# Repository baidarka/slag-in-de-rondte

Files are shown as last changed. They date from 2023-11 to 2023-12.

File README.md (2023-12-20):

# README

## Intro

The board game '[Slag in de Rondte](https://www.slaginderondte.nl/spel)' is played on a map of the Dutch Wadden Sea.  
Sail to all isles (use of engine or GPS is not allowed) and return to Harlingen. Day and night. Fastest wins.  
This project lights up the lighthouses (using real world characteristics)!

Slag in de Rondte extension (https://youtu.be/sG-JDIeeyXA)

This [repository](https://github.com/baidarka/slag-in-de-rondte) contains MicroPython code to fade multiple LEDs independently.  
Written for, and tested on, [Raspberry Pi Pico](https://www.raspberrypi.com/documentation/microcontrollers/raspberry-pi-pico.html).

The board game uses a day/night cycle of about eight minutes.
Switch off your room lights when the lighthouses come on.
And turn your room lights back on, when the lighthouses switch off. (note: an 'always on' mode is available)

## Getting started

Get started with your Raspberry Pi Pico: <https://projects.raspberrypi.org/en/projects/getting-started-with-the-pico>

### part 1

For lookenspeepers, build this project and watschen der Blinkenlichten!

- Wire up your RPI Pico according to the Fritzing diagram below
- (optional: ground GPIO2 with a resistor to bypass the 8 minutes day/night cycle and be 'always on')
- Save the script 'slag-in-de-rondte.py' to your Pico as 'main.py'
- Restart your Pico

YouTube, the plain RPI Pico project:  
Slag in de Rondte, plain RPI Pico project (https://youtu.be/appXGaQrQTM)

### part 2

After finishing part 1, install the LED's in the game board.

- Solder cheap speaker cable to the LEDs, to extend their connectors
- Gently punch holes in the game board at the 5 island lighthouses, and Harlingen Harbor
- Place the LED's in the board game
  (use the red and green LEDs at Harlingen Haven)
- Connect the LED wires to your breadboard as before
  (do not change the circuit, leave the resistors in place)

YouTube, the complete game board install:  
Slag in de Rondte extension, complete game board install (https://youtu.be/sG-JDIeeyXA)

## Software

The code uses Pulse Width Modulation (PWM) and async I/O:

- `PWM` allows fading of a LED on a digital port.
- the `uasyncio` library allows for cooperative concurrent task execution.

Tested on a RPI Pico, using MicroPython 1.21.0.

Tip: check for MicroPython linting
<https://github.com/Josverl/micropython-stubber#boost-micropython-productivity-in-vscode>

I wrote this code to learn Python.
Please feel free to post issues on effectiveness, maintainability, style etc.

## Parts, wiring, pinout

| item | quantity |
| --- | --- |
| RaspberryPi Pico H | 1 |
| LED white (5mm) | 5 |
| LED red (5mm) | 1 |
| LED green (5mm) | 1 |
| resistor 1kΩ | 7 |
| breadboard | 1 |
| hollow pipe tool 4mm  | 1 |
| speaker cable (thin)  | 3 meters |

A [RPI Pico](https://www.raspberrypi.com/documentation/microcontrollers/raspberry-pi-pico.html)
costs about €6.- at [Kiwi](https://www.kiwi-electronics.com/nl/raspberry-pi-pico-h-10939),
a breadboard (400 points) costs about €4.-.  
A hollow pipe tool (Dutch: holpijp) is only needed if you want to punch holes in your game board, to fit the LEDs.  

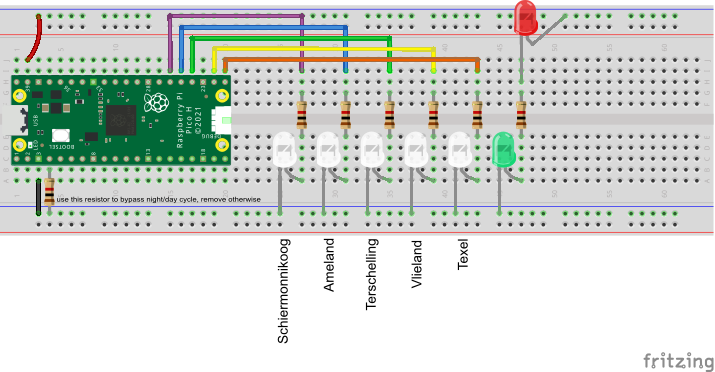
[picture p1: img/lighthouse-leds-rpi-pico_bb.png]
Lighthouse LEDs


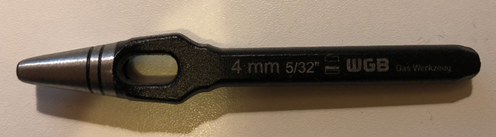
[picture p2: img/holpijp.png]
Hollow pipe tool


| pin | pin name | in/out | description |
| --- | --- | --- | --- |
|  3  | GND | | ground |
|  4  | GPIO 2 | in | disables night-and-day cycle |
| 21  | GPIO 16  | out 3.3V | LED Texel |
| 22  | GPIO 17  | out 3.3V | LED Vlieland |
| 24  | GPIO 18  | out 3.3V | LED Terschelling |
| 25  | GPIO 19  | out 3.3V | LED Ameland |
| 26  | GPIO 20  | out 3.3V | LED Schiermonnikoog |
| 39  | VSYS | 5V | LED Red + Green Harlingen |

CAUTION:
Drawing too much power from the board may damage the board.  
Thus use resistors to drive the LEDs.  
For tinkering only. Use at your own risk.

If you want to 'separate the controller from the power', you can add a PCA9685 in the mix.  
The PCA9685 (a servo driver) has it's own power, can be controlled using I2C, and supports PWM.  
I picked one up for €8.-. Possibly more on that later.

## Contributions

Feel free to contribute, in bite-size PR's. :)  
Please be nice!

Sound? Listen in on [VHF Brandaris](http://www.tbandsma.nl/index.php/scanner/).  :)
To all board players, seamen, skippers, schippers and Schiffer:
Fair winds and following seas!

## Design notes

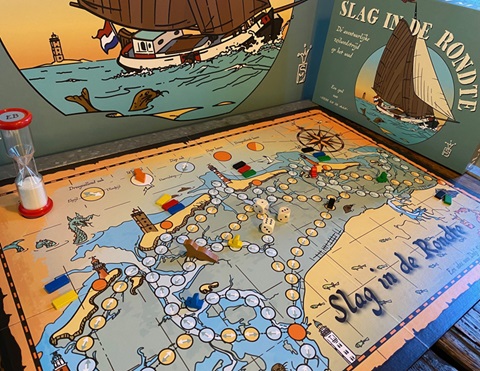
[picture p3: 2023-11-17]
img/SlagInDeRondte-bordspel-small.jpg

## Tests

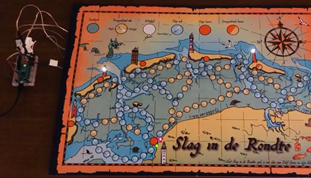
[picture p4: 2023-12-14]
img/slag-in-de-rondte-project-result-small.png

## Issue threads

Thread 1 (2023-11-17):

feature: day-nacht cyclus

baidarka, 2023-11-17:
Het spel kent getij (eb en vloed) met een cyclus van 4 minuten (zandloper). Laat de lampjes 8 minuten branden (nacht) en zet ze daarna 8 minuten uit (dag). Bouw deze cyclus in, in de code.

Closed 2023-11-22.

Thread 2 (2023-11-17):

feature: verlichting havenhoofd Harlingen

baidarka, 2023-11-17:
Zet een paar pinnen aan om het havenhoofd van Harlingen te kunnen verlichten met een rode en groene LED.
(wire diagram aanpassen, power draw nogmaals overwegen)

Closed 2023-11-23.

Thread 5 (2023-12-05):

Fritzing diagram has one wire too many.

baidarka, 2023-12-05:
**Describe the bug**
Fritzing diagram uses a long plus (red) wire on top, which is not needed. Pls remove for completeness.

**To Reproduce**
(see diagram)

**Expected behavior**
Beautification...

Closed 2023-12-07.

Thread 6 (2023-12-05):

Document the optional use of a PCA9586 controller

baidarka, 2023-12-05:
**Is your feature request related to a problem? Please describe.**
When (if) i want to expand on this project (more LEDs or adding servos) i need more power than the Pico can deliver. Adding a PCA9586 can alleviate this issue.

**Describe the solution you'd like**
Document the (potential) use of a PCA9685...

Closed 2023-12-07.

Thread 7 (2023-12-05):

Add a bypass of the day/night feature

baidarka, 2023-12-05:
**Is your feature request related to a problem? Please describe.**
The current code uses an undocumented cycle of 8 minutes 'day' and 8 minutes 'night'. Add a simple switch (pull_up wire) to make it possible to be always 'on' (night mode).

Closed 2023-12-09.

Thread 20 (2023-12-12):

document the use of the use of this project when playing the boardgame

baidarka, 2023-12-12:
**Is your feature request related to a problem? Please describe.**
write a separate MD file, specific for the game

**Describe the solution you'd like**
A clear and concise description of what you want to happen.

**Describe alternatives you've considered**
A clear and concise description of any alternative solutions or features you've considered.

**Additional context**
Add any other context or screenshots about the feature request here.

Closed 2023-12-14.

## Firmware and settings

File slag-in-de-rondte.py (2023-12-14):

#######################################################################
# Project site: https://github.com/baidarka/slag-in-de-rondte
# Fade five LEDs independently.
# Fading patterns are the characteristics of five Dutch lighthouses.
# Tested on Raspberry Pi Pico with MicroPython 1.21.0.
#
# An extension project for the Dutch board game: Slag in de Rondte
# https://www.slaginderondte.nl/spel
#
# Author: @baidarka, 2023
#######################################################################
from machine import ADC, Pin, PWM
from time import sleep
import gc
import math
import random
import time
import uasyncio

duty_max = 65535  # max duty cycle of RPI RP2xxx; MicroPython quickref
f = 1000 # frequency (Hz), just pick one quicker than the human eye 

# Assign each lighthouse a PWM object (a LED on a GPIO pin)
texel           = PWM(Pin(16), f)
vlieland        = PWM(Pin(17), f)
terschelling    = PWM(Pin(18), f)
ameland         = PWM(Pin(19), f)
schiermonnikoog = PWM(Pin(20), f)

# Optionally, run without night_n_day cycle
#  - pin not grounded = night and day cycle of 8 minutes
#  - pin grounded     = continuously use LEDs 
night_n_day     = Pin(2, Pin.IN, Pin.PULL_UP)

# Coroutine
async def flash(pwm):
  """Fade a LED on and off, using Pulse Width Modulation

  A lighthouse 'flash' may take 2 seconds or more. 
  Light off ==> 'duty cycle = 0'. 
  Light on  ==> 'duty cycle = duty_max'. 

  Parameters
  ----------
  pwm : PWM
      A PWM object representing a LED.
      
  Returns
  -------
  None
  """
  for i in range(100):
    # Using sin() is just a snazzy way of getting increasing and
    # descreasing fractions in one loop...
    fraction = math.sin(i/100 * math.pi)
    pwm.duty_u16(round(fraction * duty_max))
    await uasyncio.sleep_ms(12)
  
  # Force light off
  pwm.duty_u16(0)
  await uasyncio.sleep_ms(1600)

# Coroutine
async def isophase(pwm, d):
  """Isophase a LED on and off, using Pulse Width Modulation

  Isophase means: 
  first half of the duration 'on', second half of the duration 'off'

  Parameters
  ----------
  pwm : PWM
      A PWM object representing a LED.
  d : int
      Duration of the entire on-and-off cycle in seconds.
      
  Returns
  -------
  None
  """
  # Light on
  for i in range(0, 100, 5):
    pwm.duty_u16(round(i/100 * duty_max))
    await uasyncio.sleep_ms(10)
  await uasyncio.sleep_ms(round(d/2) * 1000)
    
  # Light off
  for i in range(100, 0, -5):
    pwm.duty_u16(round(i/100 * duty_max))
    await uasyncio.sleep_ms(10)
  pwm.duty_u16(0)
  await uasyncio.sleep_ms(round(d/2) * 1000)

# Coroutine
async def fade_out(pwm):
  """Fade out a LED, to stop the current task"""
  # Get the current duty cycle and fade out from there.
  current_duty_cycle = pwm.duty_u16()
  current_duty_cycle_fraction = (current_duty_cycle // (duty_max/100))
  
  # Light off
  for i in range(current_duty_cycle_fraction, 0, -2):
    pwm.duty_u16(round(i/100 * duty_max))
    await uasyncio.sleep_ms(12)
  pwm.duty_u16(0)  

# Coroutine
async def random_delay():
  """Random delay of at most 5 seconds"""
  max_msec = 5000
  delay_ms = math.floor(random.random() * max_msec)
  await uasyncio.sleep_ms(delay_ms)

# Coroutine: characteristics of light: Texel FL(2) W 10s
async def characteristics_texel(texel):
  await random_delay()

  while True:
    try:
      time_begin = time.ticks_ms()
      await flash(texel)
      await flash(texel)
      time_elapsed = time.ticks_ms() - time_begin
      await uasyncio.sleep_ms(10000 - time_elapsed)
      
    except (uasyncio.CancelledError):
      await random_delay()

      # Switch off
      await fade_out(texel)
      print('Task Texel cancelled')
      raise

# Coroutine: characteristics of light: Vlieland ISO W 4s
async def characteristics_vlieland(vlieland):
  await random_delay()

  while True:
    try:
      await isophase(vlieland, 4)

    except (uasyncio.CancelledError):
      await random_delay()

      # Switch off
      await fade_out(vlieland)
      print('Task Vlieland cancelled')
      raise

# Coroutine: characteristics of light: Terschelling FL(1) W 5s
async def characteristics_terschelling(terschelling):
  await random_delay()

  while True:
    try:
      time_begin = time.ticks_ms()
      await flash(terschelling)
      time_elapsed = time.ticks_ms() - time_begin
      await uasyncio.sleep_ms(5000 - time_elapsed)

    except (uasyncio.CancelledError):
      await random_delay()

      # Switch off
      await fade_out(terschelling)
      print('Task Terschelling cancelled')
      raise

#Coroutine: characteristics of light: Ameland FL(3) W 15s
async def characteristics_ameland(ameland):
  await random_delay()

  while True:
    try:
      time_begin = time.ticks_ms()
      await flash(ameland)
      await flash(ameland)
      await flash(ameland)
      time_elapsed = time.ticks_ms() - time_begin
      await uasyncio.sleep_ms(15000 - time_elapsed)

    except (uasyncio.CancelledError):
      await random_delay()

      # Switch off
      await fade_out(ameland)
      print('Task Ameland cancelled')
      raise

# Coroutine: characteristics of light: Schiermonnikoog FL(4) W 20s
async def characteristics_schiermonnikoog(schiermonnikoog):
  await random_delay()

  while True:
    try:
      time_begin = time.ticks_ms()
      await flash(schiermonnikoog)
      await flash(schiermonnikoog)
      await flash(schiermonnikoog)
      await flash(schiermonnikoog)
      time_elapsed = time.ticks_ms() - time_begin
      await uasyncio.sleep_ms(20000 - time_elapsed)
      
    except (uasyncio.CancelledError):
      await random_delay()

      # Switch off
      await fade_out(schiermonnikoog)
      print('Task Schiermonnikoog cancelled')
      raise
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

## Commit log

2023-11-17 added fritzing labels
    [lighthouse-leds-1.fzz]
2023-11-23 added fixed harbor lights
    [lighthouse-leds-1.fzz]
2023-12-07 fixed wiring diagram, tidied the docs
    [lighthouse-leds-1.fzz]
2023-12-08 Fix/docs clarity (#9)
    * docs
    * added explicit gc
    [slag-in-de-rondte.py]
2023-12-08 still unfinished work (#11)
    * max duty cycle
    * removed debug value
    * pin number
2023-12-08 Fix/diagram (#12)
    * fix led order in diagram
    * fzz
    [lighthouse-leds-1.fzz]
2023-12-09 day night bypass (#16)
    * functional grounding test
    * added day and night cycle
    * daily cycle
2023-12-10 Randomized stop and start (#18)
    * added random delay for start and stop
    * docs night-n-day
    [lighthouse-leds-1.fzz]
